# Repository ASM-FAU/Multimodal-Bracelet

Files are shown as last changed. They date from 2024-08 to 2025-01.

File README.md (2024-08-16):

# Multimodal-Bracelet
This project provides electrical and mechanical plans such as all software to build a multimodal bracelet that can be used to acquire muscular activity. The bracelet is designed around the commercial Avanti Trigno EMG sensors by Delsys. We combine each EMG sensor with 4 FMG sensors (FSRs). That way each module can acquire EMG and IMU data by the Avanti Trigno sensors and FMG. The following Figure shows how we combined the multiple modalities in a single module.

<p align="center">
  
</p>

The following Figre shows a rough outline of the PCB layout which are provided within this project.
<p align="center">
  
</p>

The pictures below shall help to get a better understanding about the design of the bracelet and shall help when replicating the device.

<p align="center">
  
  
  <br>
  
  
</p>

<p align="center">
  
  
  <br>
  
  
</p>

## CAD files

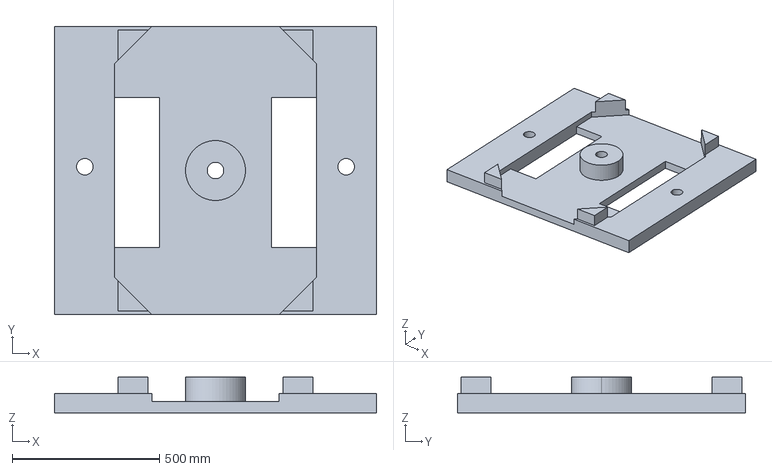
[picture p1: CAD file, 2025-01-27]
CAD/v2/main_fsr_cover.stp
1092.2 x 977.9 x 120.6 mm

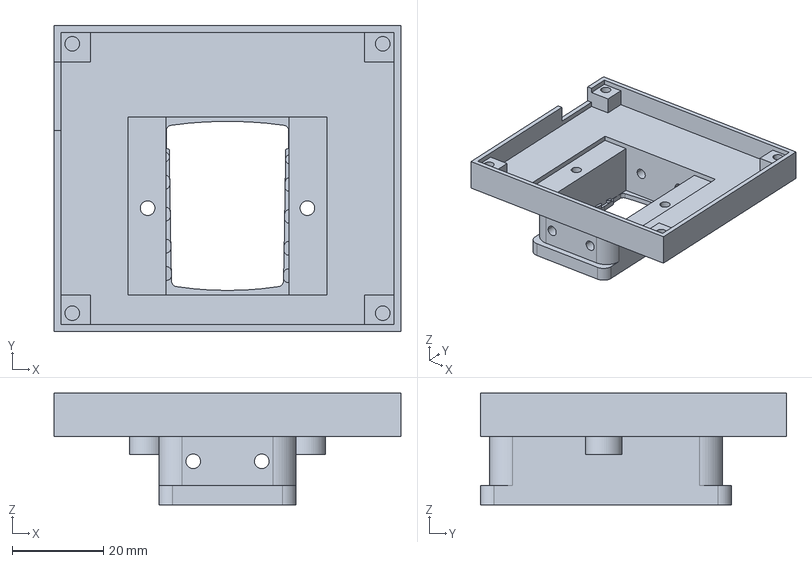
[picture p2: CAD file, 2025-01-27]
CAD/v2/main_base.stp
76.0 x 67.0 x 24.5 mm

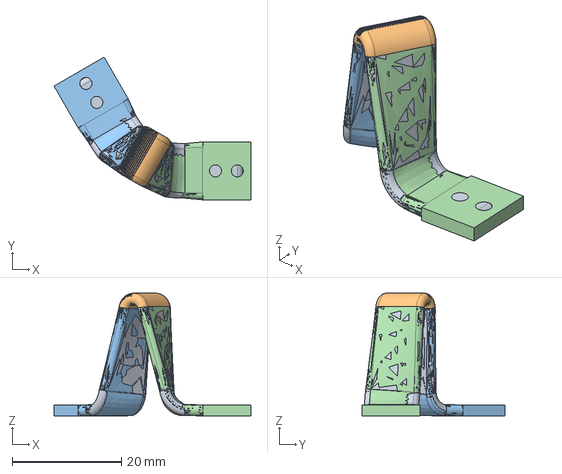
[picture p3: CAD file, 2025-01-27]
CAD/v2/flexible_link_adjustable.stp
36.1 x 26.1 x 22.5 mm

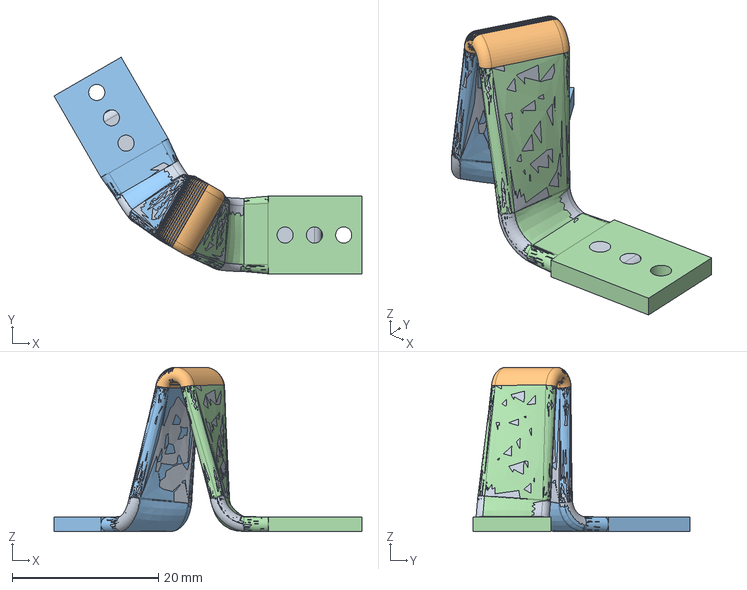
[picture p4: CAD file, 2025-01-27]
CAD/v2/flexible_link_adjustable_long.stp
42.1 x 29.6 x 22.5 mm

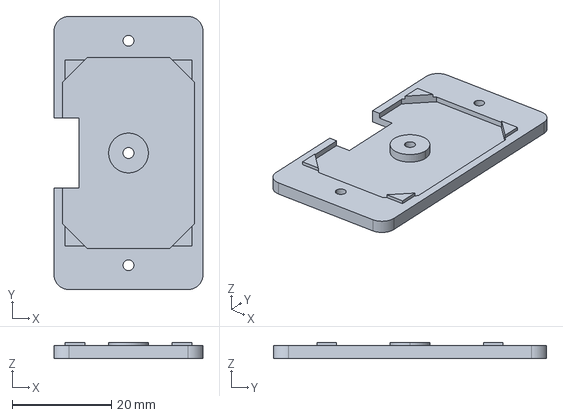
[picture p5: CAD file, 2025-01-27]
CAD/v2/sub_cover_new.stp
30.0 x 55.0 x 3.25 mm

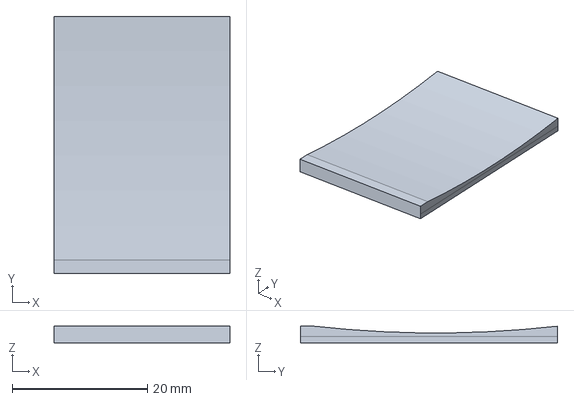
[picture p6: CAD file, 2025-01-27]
CAD/v2/sub_force_transmitter.stp
26.0 x 38.0 x 2.46 mm

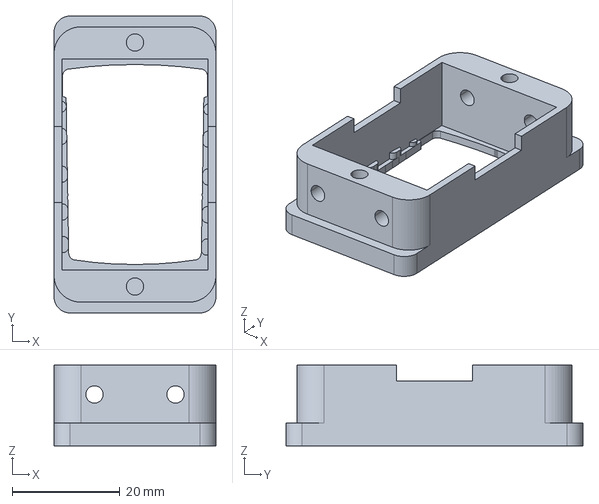
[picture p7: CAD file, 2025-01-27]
CAD/v2/emg_sub_bottem.stp
30.0 x 55.0 x 15.0 mm

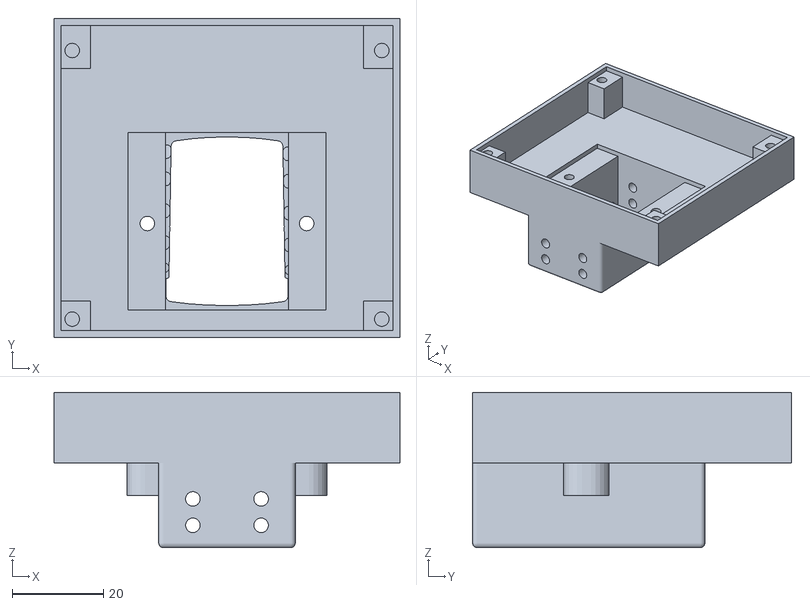
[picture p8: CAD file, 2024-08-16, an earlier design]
CAD/v1/Main/Base/main_base.stl
76.0 x 70.0 x 34.1

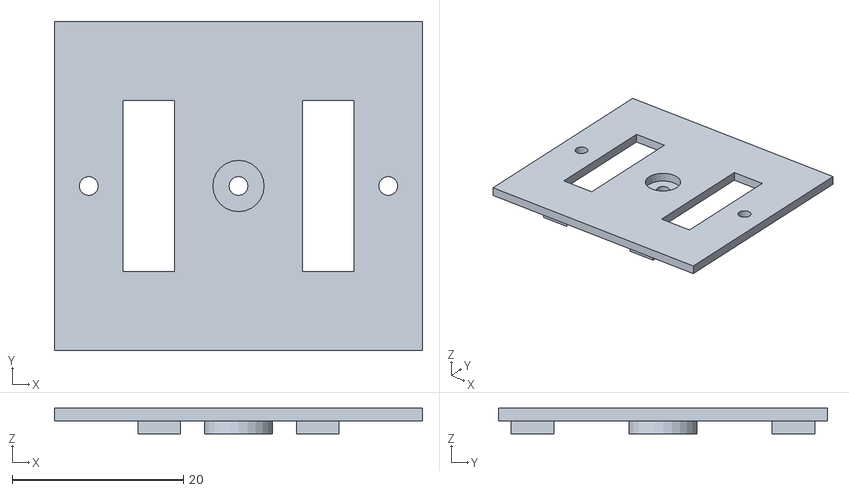
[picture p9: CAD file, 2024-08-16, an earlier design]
CAD/v1/Main/FSR_Cover/main_fsr_cover.stl
43.0 x 38.4 x 3.00

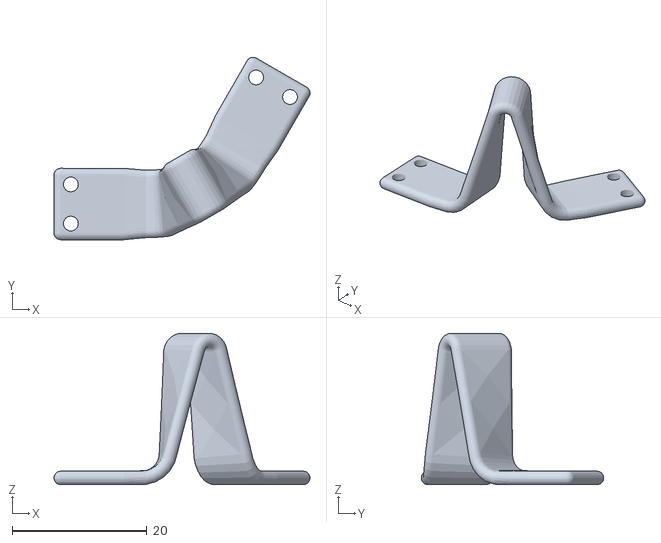
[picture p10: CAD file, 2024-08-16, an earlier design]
CAD/v1/Link/flexible_link_medium.stl
37.9 x 27.1 x 22.4

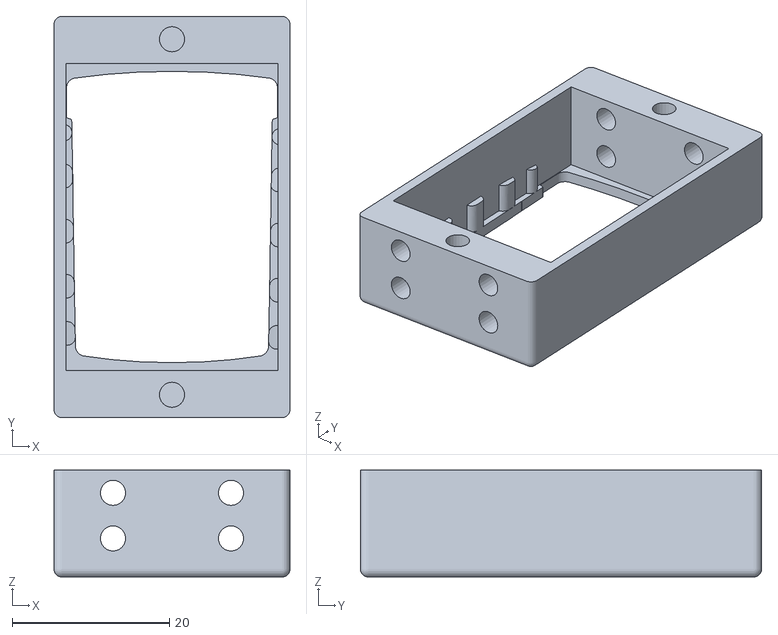
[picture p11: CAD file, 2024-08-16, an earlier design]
CAD/v1/Sub/sub_base.stl
30.0 x 51.0 x 13.6

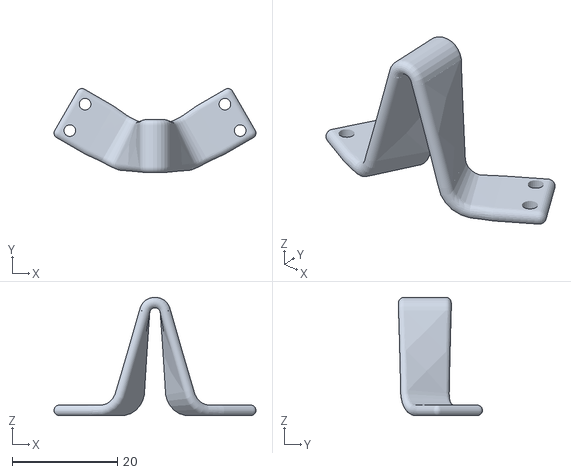
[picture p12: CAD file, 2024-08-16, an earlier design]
CAD/v1/Link/flexible_link_short.stl
38.3 x 15.9 x 22.4

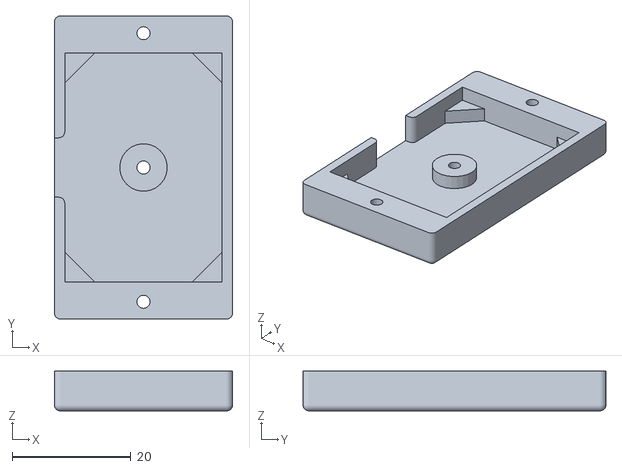
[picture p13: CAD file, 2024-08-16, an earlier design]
CAD/v1/Sub/sub_cover.stl
30.0 x 51.0 x 6.70

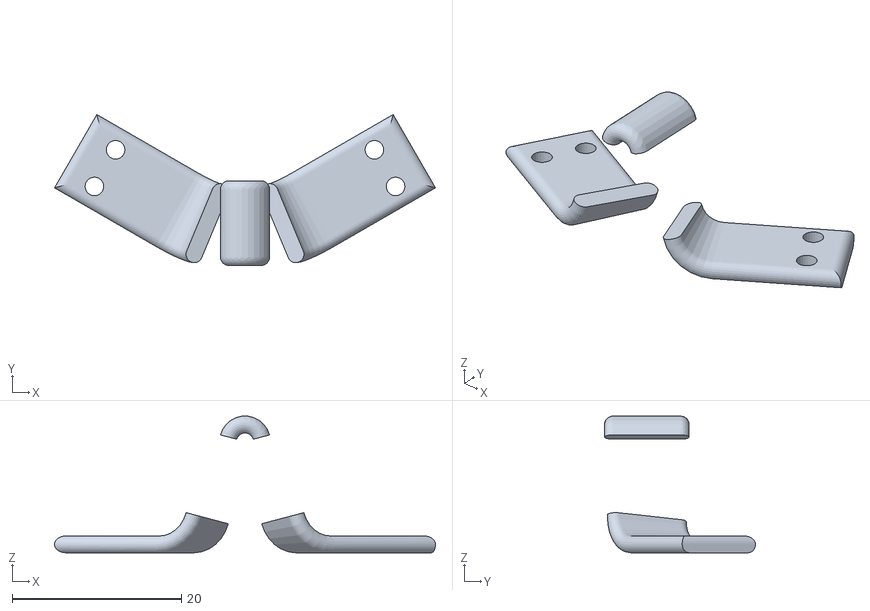
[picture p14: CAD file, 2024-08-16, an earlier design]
CAD/v1/Link/flexible_link_long.stl
45.0 x 17.8 x 16.1

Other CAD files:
CAD/v1/Sub/sub_cover_emg_only.stl
CAD/v1/Sub/sub_force_transmitter.stl
CAD/v1/Main/Base/main_base.dwg
CAD/v1/Main/FSR_Cover/main_fsr_cover.dwg
CAD/v2/emg_sub_bottem.stl
CAD/v2/flexible_link_adjustable.stl
CAD/v2/flexible_link_adjustable_long.stl
CAD/v2/main_base.stl
CAD/v2/main_fsr_cover.stl
CAD/v2/sub_cover_new.stl
CAD/v2/sub_force_transmitter.stl

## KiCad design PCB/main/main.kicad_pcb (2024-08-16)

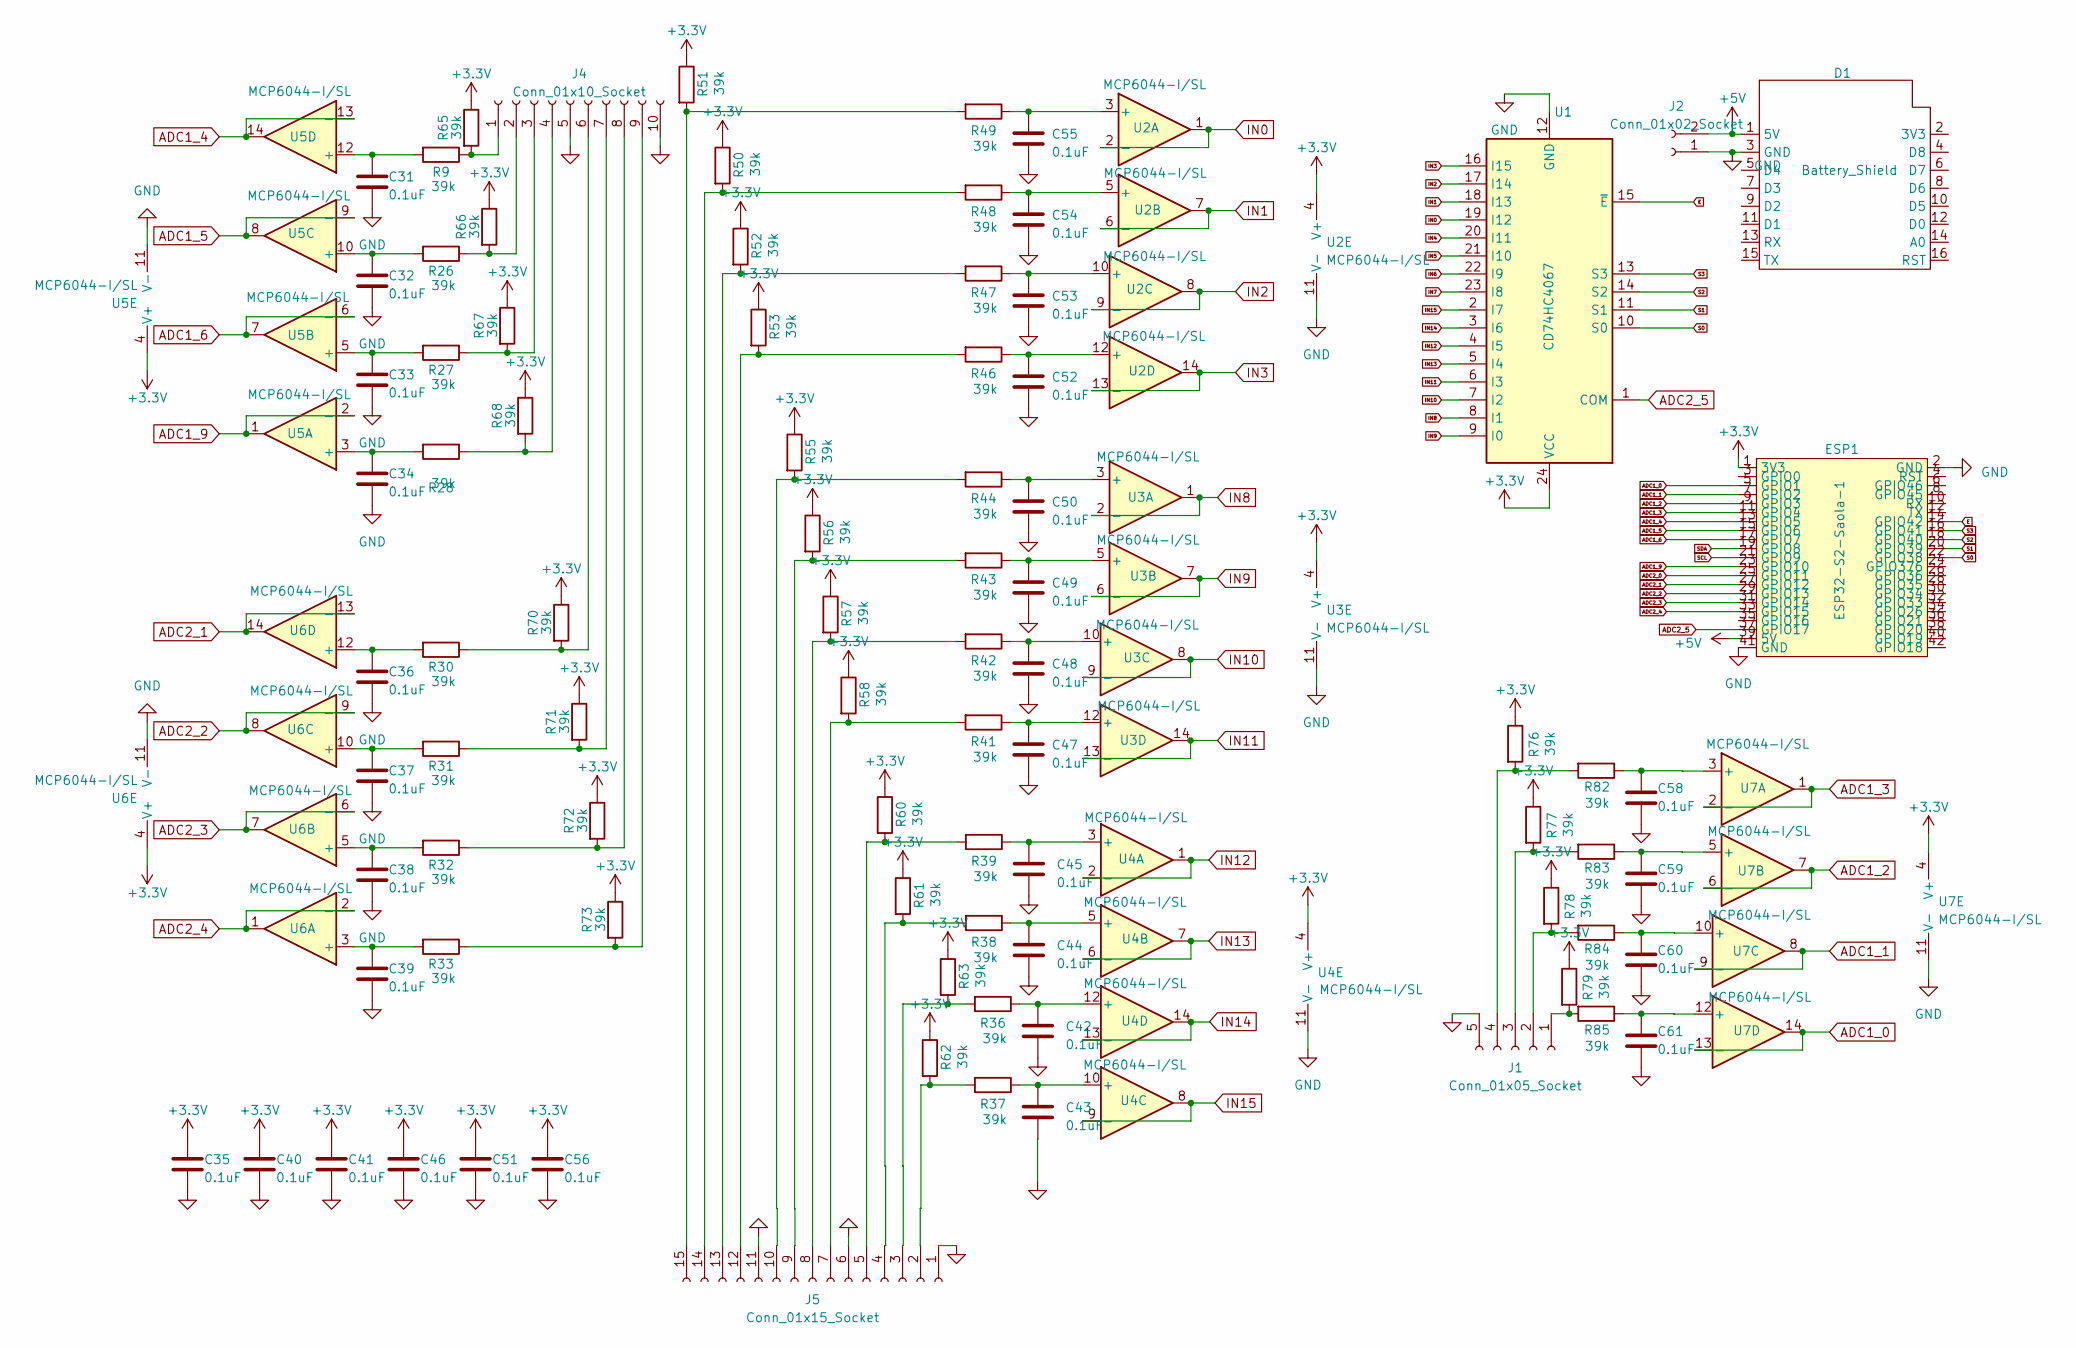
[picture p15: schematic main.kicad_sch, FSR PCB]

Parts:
C31, C32, C33, C34, C35, C36, C37, C38, C39, C40, C41, C42, C43, C44, C45, C46, C47, C48, C49, C50, C51, C52, C53, C54, C55, C56, C58, C59, C60, C61: 0.1uF; C_0603_1608Metric_Pad1.08x0.95mm_HandSolder; MFR Part CL10A104KA8NNNC; JLCPCB Part C2762593
D1: Battery_Shield; Battery Shield
ESP1: ESP32-S2-Saola-1
J1: Conn_01x05_Socket; PinSocket_1x05_P2.54mm_Vertical
J2: Conn_01x02_Socket; PinSocket_1x02_P2.54mm_Vertical
J4: Conn_01x10_Socket; PinSocket_1x10_P2.54mm_Vertical
J5: Conn_01x15_Socket; PinSocket_1x15_P2.54mm_Vertical
R9, R26, R27, R28, R30, R31, R32, R33, R36, R37, R38, R39, R41, R42, R43, R44, R46, R47, R48, R49, R50, R51, R52, R53, R55, R56, R57, R58, R60, R61, R62, R63, R65, R66, R67, R68, R70, R71, R72, R73, R76, R77, R78, R79, R82, R83, R84, R85: 39k; R_0603_1608Metric_Pad0.98x0.95mm_HandSolder; MFR Part ES03W4F3902T5E; JLCPCB Part C2772794
U1: CD74HC4067; SOIC-24W_7.5x15.4mm_P1.27mm; MFR Part CD74HC4067M; JLCPCB Part C1545936
U2, U3, U4, U5, U6, U7: MCP6044-I/SL; MCP6044ISL; MFR Part MCP6044-I/SL; JLCPCB Part C50260

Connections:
+3.3V: C35.1, C40.1, C41.1, C46.1, C51.1, C56.1, ESP1.1 (3V3), R50.1, R51.1, R52.1, R53.1, R55.1, R56.1, R57.1, R58.1, R60.1, R61.1, R62.1, R63.1, R65.1, R66.1, R67.1, R68.1, R70.1, R71.1, R72.1, R73.1, R76.1, R77.1, R78.1, R79.1, U1.24 (VCC), U2.4 (V+), U3.4 (V+), U4.4 (V+), U5.4 (V+), U6.4 (V+), U7.4 (V+)
+5V: D1.1 (5V), ESP1.39 (5V), J2.2
ADC1_0: ESP1.5 (GPIO1), U7.13 (-), U7.14
ADC1_1: ESP1.7 (GPIO2), U7.8, U7.9 (-)
ADC1_2: ESP1.9 (GPIO3), U7.6 (-), U7.7
ADC1_3: ESP1.11 (GPIO4), U7.1, U7.2 (-)
ADC1_4: ESP1.13 (GPIO5), U5.13 (-), U5.14
ADC1_5: ESP1.15 (GPIO6), U5.8, U5.9 (-)
ADC1_6: ESP1.17 (GPIO7), U5.6 (-), U5.7
ADC1_9: ESP1.23 (GPIO10), U5.1, U5.2 (-)
ADC2_0: ESP1.25 (GPIO11)
ADC2_1: ESP1.27 (GPIO12), U6.13 (-), U6.14
ADC2_2: ESP1.29 (GPIO13), U6.8, U6.9 (-)
ADC2_3: ESP1.31 (GPIO14), U6.6 (-), U6.7
ADC2_4: ESP1.33 (GPIO15), U6.1, U6.2 (-)
ADC2_5: ESP1.37 (GPIO17), U1.1 (COM)
E: ESP1.14 (GPIO42), U1.15 (~E)
GND: C31.2, C32.2, C33.2, C34.2, C35.2, C36.2, C37.2, C38.2, C39.2, C40.2, C41.2, C42.2, C43.2, C44.2, C45.2, C46.2, C47.2, C48.2, C49.2, C50.2, C51.2, C52.2, C53.2, C54.2, C55.2, C56.2, C58.2, C59.2, C60.2, C61.2, D1.3 (GND), ESP1.2 (GND), ESP1.41 (GND), J1.5, J2.1, J4.5, J4.10, J5.1, J5.6, J5.11, U1.12 (GND), U2.11 (V-), U3.11 (V-), U4.11 (V-), U5.11 (V-), U6.11 (V-), U7.11 (V-)
IN0: U1.19 (I12), U2.1, U2.2 (-)
IN1: U1.18 (I13), U2.6 (-), U2.7
IN2: U1.17 (I14), U2.8, U2.9 (-)
IN3: U1.16 (I15), U2.13 (-), U2.14
IN4: U1.20 (I11)
IN5: U1.21 (I10)
IN6: U1.22 (I9)
IN7: U1.23 (I8)
IN8: U1.8 (I1), U3.1, U3.2 (-)
IN9: U1.9 (I0), U3.6 (-), U3.7
IN10: U1.7 (I2), U3.8, U3.9 (-)
IN11: U1.6 (I3), U3.13 (-), U3.14
IN12: U1.4 (I5), U4.1, U4.2 (-)
IN13: U1.5 (I4), U4.6 (-), U4.7
IN14: U1.3 (I6), U4.13 (-), U4.14
IN15: U1.2 (I7), U4.8, U4.9 (-)
unnamed: J1.1, R79.2, R85.2
unnamed: J1.2, R78.2, R84.2
unnamed: J1.3, R77.2, R83.2
unnamed: J1.4, R76.2, R82.2
unnamed: J4.1, R9.1, R65.2
unnamed: J4.2, R26.1, R66.2
unnamed: J4.3, R27.1, R67.2
unnamed: J4.4, R28.1, R68.2
unnamed: J4.6, R30.1, R70.2
unnamed: J4.7, R31.1, R71.2
unnamed: J4.8, R32.1, R72.2
unnamed: J4.9, R33.1, R73.2
unnamed: J5.2, R37.2, R62.2
unnamed: J5.3, R36.2, R63.2
unnamed: J5.4, R38.2, R61.2
unnamed: J5.5, R39.2, R60.2
unnamed: J5.7, R41.2, R58.2
unnamed: J5.8, R42.2, R57.2
unnamed: J5.9, R43.2, R56.2
unnamed: J5.10, R44.2, R55.2
unnamed: J5.12, R46.2, R53.2
unnamed: J5.13, R47.2, R52.2
unnamed: J5.14, R48.2, R50.2
unnamed: J5.15, R49.2, R51.2
unnamed: C55.1, R49.1, U2.3 (+)
unnamed: C54.1, R48.1, U2.5 (+)
unnamed: C53.1, R47.1, U2.10 (+)
unnamed: C52.1, R46.1, U2.12 (+)
unnamed: C50.1, R44.1, U3.3 (+)
unnamed: C49.1, R43.1, U3.5 (+)
unnamed: C48.1, R42.1, U3.10 (+)
unnamed: C47.1, R41.1, U3.12 (+)
unnamed: C45.1, R39.1, U4.3 (+)
unnamed: C44.1, R38.1, U4.5 (+)
unnamed: C43.1, R37.1, U4.10 (+)
unnamed: C42.1, R36.1, U4.12 (+)
unnamed: C34.1, R28.2, U5.3 (+)
unnamed: C33.1, R27.2, U5.5 (+)
unnamed: C32.1, R26.2, U5.10 (+)
unnamed: C31.1, R9.2, U5.12 (+)
unnamed: C39.1, R33.2, U6.3 (+)
unnamed: C38.1, R32.2, U6.5 (+)
unnamed: C37.1, R31.2, U6.10 (+)
unnamed: C36.1, R30.2, U6.12 (+)
unnamed: C58.1, R82.1, U7.3 (+)
unnamed: C59.1, R83.1, U7.5 (+)
unnamed: C60.1, R84.1, U7.10 (+)
unnamed: C61.1, R85.1, U7.12 (+)
S0: ESP1.22 (GPIO38), U1.10 (S0)
S1: ESP1.20 (GPIO39), U1.11 (S1)
S2: ESP1.18 (GPIO40), U1.14 (S2)
S3: ESP1.16 (GPIO41), U1.13 (S3)
SCL: ESP1.21 (GPIO9)
SDA: ESP1.19 (GPIO8)

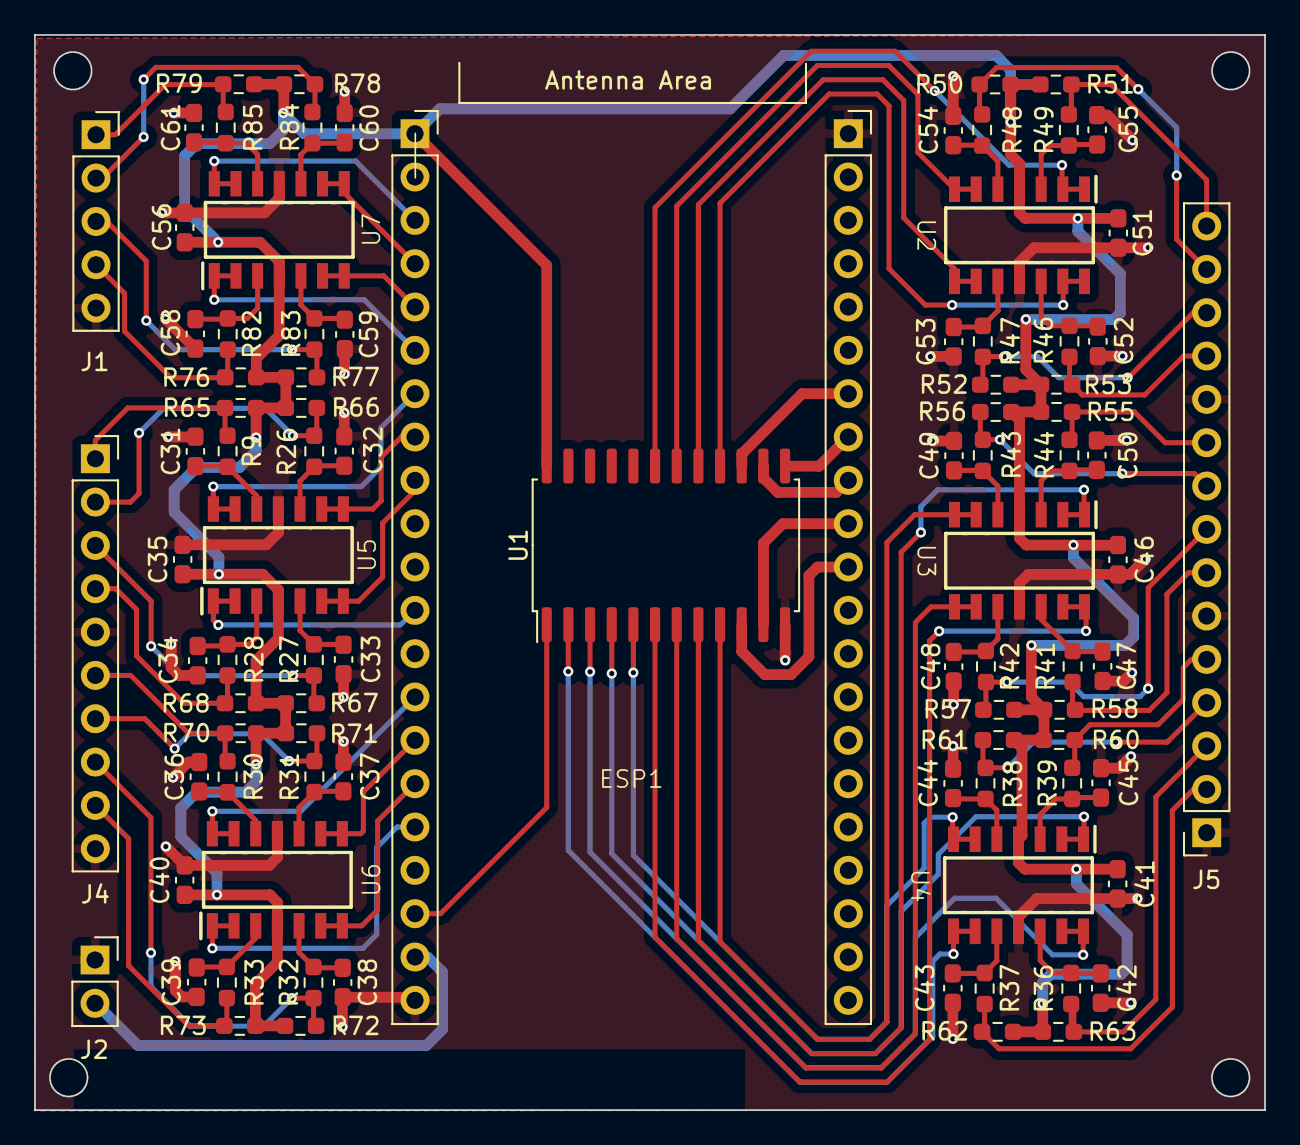
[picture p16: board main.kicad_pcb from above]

Board: 2 copper layers, 72.1 x 63.0 mm, 90 parts (0 on the bottom side), 81 nets.

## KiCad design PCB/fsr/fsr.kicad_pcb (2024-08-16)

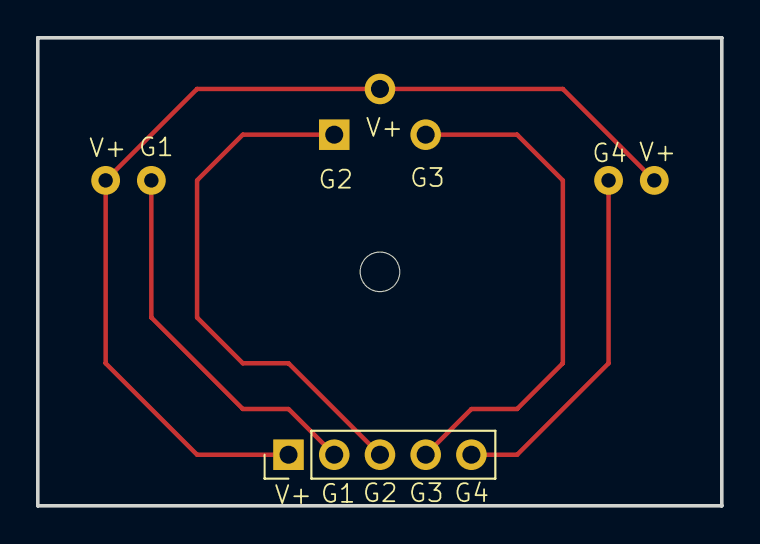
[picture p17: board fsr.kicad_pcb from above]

Board: 2 copper layers, 38.0 x 26.0 mm, 5 parts (0 on the bottom side), 5 nets.

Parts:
H1: MountingHole; MountingHole_2.2mm_M2
J1: Conn_01x05; PinHeader_1x05_P2.54mm_Vertical
J5: Conn_01x03_Pin; PinHeader_1x03_P2.54mm_Vertical
R1, R4: R; R_LDR_4.9x4.2mm_P2.54mm_Vertical

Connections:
unnamed: J1.1, J5.2, R1.1, R4.2
unnamed: J1.2, R1.2
unnamed: J1.3, J5.1
unnamed: J1.4, J5.3
unnamed: J1.5, R4.1

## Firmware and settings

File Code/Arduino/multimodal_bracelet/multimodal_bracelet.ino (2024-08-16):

#include <WiFi.h>
#include <PubSubClient.h>
#include <Adafruit_NeoPixel.h>
#include <time.h>
#include <NTPClient.h>
#include <WiFiUdp.h>
#include <ArduinoJson.h>

// Replace with your WiFi settings
const char* ssid = "enter your WiFi SSID";  // Input your SSID here
const char* password = "enter your WiFi password"; // Input your password here

// Replace with your MQTT server settings
const char* mqtt_server = "enter IP adress";
const int mqtt_port = 1883;
const char* mqtt_topic = "fmg_data";

// NTP server details
const char* ntpServer = "pool.ntp.org";
const long  gmtOffset_sec = 3600;
const int   daylightOffset_sec = 3600;

// Variable for storing the previous second for comparison
int prevSecond = -1;

struct tm timeinfo;
unsigned long startMillis;

// Variable to store the latest timestamp
unsigned long long latestTimestamp = 0;

// Pin definitions
#define FSR0_0 1
#define FSR0_1 2
#define FSR0_2 3
#define FSR0_3 4
#define FSR1_0 5
#define FSR1_1 6
#define FSR1_2 7
#define FSR1_3 10
#define FSR2_0 12
#define FSR2_1 13
#define FSR2_2 14
#define FSR2_3 15
#define MIX 17
#define E 42
#define S3 41
#define S2 40
#define S1 39
#define S0 38

// Number of sensors and values per sensor
#define NUM_SEN         6
#define VAL_PER_SEN     4
#define NUM_DATA        (NUM_SEN * VAL_PER_SEN)
#define NUM_DIREKT_READ 12
#define NUM_MIX         (NUM_DATA - NUM_DIREKT_READ)

uint8_t sensor_pins[NUM_DIREKT_READ] = {FSR0_0, FSR0_1, FSR0_2, FSR0_3, FSR1_0, FSR1_1, FSR1_2, FSR1_3, FSR2_0, FSR2_1, FSR2_2, FSR2_3};

float fmg_data[NUM_DATA] = {0};

// LED settings
#define PIN            18
#define NUMPIXELS      1
#define BRIGHTNESS     50
Adafruit_NeoPixel pixels(NUMPIXELS, PIN, NEO_GRB + NEO_KHZ800);
int LED_flag = 0;

WiFiClient espClient;
PubSubClient client(espClient);

void setup() {
  Serial.begin(115200);
  
  setup_pin();
  setup_led(); 
  setup_wifi(); // Connect to WiFi network
  
  client.setServer(mqtt_server, mqtt_port); // Set MQTT server
  client_connection();

  // Initialize NTP
  configTime(gmtOffset_sec, daylightOffset_sec, ntpServer);

  getLocalTime(&timeinfo); 
  int currentSecond = timeinfo.tm_sec;
  prevSecond = currentSecond;
  while (true) {      
    getLocalTime(&timeinfo); // Fetch the current time
    int currentSecond = timeinfo.tm_sec;
    if (currentSecond != prevSecond) {
      break; // Break the loop when the second changes
    }
  }
  startMillis = millis();   
}

void setup_pin() {
  // Initialize pin modes
  pinMode(FSR0_0, INPUT);
  pinMode(FSR0_1, INPUT);
  pinMode(FSR0_2, INPUT);
  pinMode(FSR0_3, INPUT);
  pinMode(FSR1_0, INPUT);
  pinMode(FSR1_1, INPUT);
  pinMode(FSR1_2, INPUT);
  pinMode(FSR1_3, INPUT);
  pinMode(FSR2_0, INPUT);
  pinMode(FSR2_1, INPUT);
  pinMode(FSR2_2, INPUT);
  pinMode(FSR2_3, INPUT);
  pinMode(MIX, INPUT);
  pinMode(E, OUTPUT);
  digitalWrite(E, HIGH);
  pinMode(S3, OUTPUT);
  digitalWrite(S3, LOW);
  pinMode(S1, OUTPUT);
  digitalWrite(S1, LOW);
  pinMode(S2, OUTPUT);
  digitalWrite(S2, LOW);
  pinMode(S0, OUTPUT);
  digitalWrite(S0, LOW);
}

void setup_led() {
  pixels.begin(); // Initialize the NeoPixel strip
  pixels.setBrightness(BRIGHTNESS); // Set brightness
  pixels.show(); // Turn off all LEDs on start
}

void led_colour() {
  // Set LED color based on connection status
  switch (LED_flag) {
    case 0:
      pixels.setPixelColor(0, pixels.Color(255, 0, 0)); // Red: initial state
      break;
    case 1:
      pixels.setPixelColor(0, pixels.Color(255, 255, 0)); // Yellow: WiFi connected
      break;
    case 2:
      pixels.setPixelColor(0, pixels.Color(0, 255, 0)); // Green: server connected
      break;
    case 3:
      pixels.setPixelColor(0, pixels.Color(0, 0, 255)); // Blue: data sending
      break;
  }
  pixels.show();  // Apply color change
}

void setup_wifi() {
  // Connect to WiFi
  WiFi.begin(ssid, password);
  while (WiFi.status() != WL_CONNECTED) {
    delay(500);
    Serial.print(".");
  }
  Serial.println("WiFi connected");
  LED_flag = 1;
  led_colour(); 
}

void reconnect() {
  // Attempt to reconnect until successful
  while (!client.connected()) {
    Serial.print("Attempting MQTT connection...");
    // Attempt to connect to the MQTT broker
    if (client.connect("mqttx_5384a150")) { // Client ID
      Serial.println("The client connection is successful");
      // Subscribe to the topic upon successful connection
      client.subscribe(mqtt_topic);
      // Send "Armband connected" message after successful connection
      const char* system_message = "Armband connected";
      client.publish(mqtt_topic, system_message);
    } else {
      Serial.print("failed, rc=");
      Serial.print(client.state());
      Serial.println(" try again in one seconds");
      // Wait 1 second before retrying
      delay(1000);
    }
  }
}

void client_connection() {
  // Check connection and reconnect if necessary
  if (!client.connected()) {
    Serial.print("client not connected");
    LED_flag = 1;
    led_colour(); // Change LED to yellow for reconnect logic
    reconnect(); // Call reconnect function
  } else {
    client.loop();
    LED_flag = 2;
    led_colour(); // Change LED to green
  }
}

void loop() {
  // Maintain network and MQTT connections
  if (WiFi.status() != WL_CONNECTED) {
  setup_wifi(); // Reconnect WiFi if necessary
  }

  if (!client.connected()) {
  reconnect(); // Try to reconnect to MQTT if necessary
  }
  client.loop(); // Maintain MQTT connection, handle incoming messages

  FSRReading();

  getLocalTime(&timeinfo);
  updateTimestamp(timeinfo);
  sendFmgDataToMQTT();
  delay(100); // Short delay for stability
}

void FSRReading() {
  // Read values from Force Sensitive Resistors (FSRs)
  Serial.println("Reading FSR values:");
  for (uint8_t sen = 0; sen < NUM_SEN; sen++) {
    Serial.print("Sensor ");
    Serial.print(sen);
    Serial.print(": ");
    for (uint8_t val = 0; val < VAL_PER_SEN; val++) {
      // Recalculate idx for global index, not distinguishing direct or mixed channel readings
      uint8_t Idx = sen * VAL_PER_SEN + val;
      
      if (Idx < NUM_DIREKT_READ) {
        // Direct readings
        fmg_data[Idx] = analogRead(sensor_pins[Idx]) * 0.08225 * (5.0 / 1023.0);
      } else {
        // Readings through mixed channel
        uint8_t mixChannel = Idx - NUM_DIREKT_READ;
        SetMixCh(mixChannel);
        fmg_data[Idx] = analogRead(MIX) * 0.08225 * (5.0 / 1023.0);
        digitalWrite(E, HIGH);
      }
      Serial.print(fmg_data[Idx]);
      Serial.print("V ");
    }
    Serial.println();
  }
}

void SetMixCh(byte Ch) {
  // Set multiplexer channels for mixed readings
  digitalWrite(E, LOW);
  digitalWrite(S0, bitRead(Ch, 0));
  digitalWrite(S1, bitRead(Ch, 1));
  digitalWrite(S2, bitRead(Ch, 2));
  digitalWrite(S3, bitRead(Ch, 3));
}

void sendFmgDataToMQTT() {
  // Calculate the total byte size needed for the data array and timestamp
  size_t dataSize = NUM_DATA * sizeof(float); // Byte size of Fmg data
  size_t timestampSize = sizeof(latestTimestamp); // Byte size of the timestamp
  size_t totalSize = dataSize + timestampSize; // Total byte size

  // Create a large enough byte array to store fmg_data and latestTimestamp
  byte dataBuffer[totalSize];

  // First, copy fmg_data into the buffer
  memcpy(dataBuffer, fmg_data, dataSize);

  // Then, copy latestTimestamp to the end of the buffer
  memcpy(dataBuffer + dataSize, &latestTimestamp, timestampSize);

  // Send binary data over MQTT
  if (!client.publish(mqtt_topic, dataBuffer, totalSize)) {
    Serial.println("Failed to publish FSR data");
  } else {
    Serial.println("FSR data published successfully");
  }
}

void updateTimestamp(struct tm &timeinfo) {
  // Construct the timestamp
  latestTimestamp = (unsigned long long)(timeinfo.tm_hour) * 10000000 +
                    (unsigned long long)(timeinfo.tm_min) * 100000 +
                    (unsigned long long)(timeinfo.tm_sec) * 1000 +
                    (unsigned long long)((millis() - startMillis) % 1000);
                    
  Serial.println(latestTimestamp); // Print the timestamp for verification
}
